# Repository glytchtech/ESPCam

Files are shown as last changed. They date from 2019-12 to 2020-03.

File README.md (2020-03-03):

# ESPCam
## STL and Configuration Files for Glytch's ESPCam Project
If you'd like to support more projects like this one, be sure to check out my [Patreon!](https://patreon.com/glytchtech)

This repo contains all the relevant files to build your own low cost, self contained ESPCam! Bill of Materials with relevant (Amazon Affiliate) links down below! 

# Camera Parts BOM: 
All links are as of December 17th, 2019
* $8.50ea ESP32 Cam Module: https://amzn.to/2Z2IYp7
* $2.50ea u.FL to SMA pig tail: https://amzn.to/2uKZqPQ
* $1.70ea Stubby Antenna 3dbi: https://amzn.to/2MbvqlQ
* $0.90ea TP4056 Battery Module: https://amzn.to/34w5ZBW
* Free 18650 Cell: Recycled from bad laptop battery 
* $7.99 CP2102 UART Programmer: https://amzn.to/2MavQcj

# Cae Parts BOM: 
All links are as of March 2nd, 2020
* $3.50ea (Needs 1) Main Buck Converter: https://amzn.to/2TzlfKO
* $1.55ea (Needs 1) 24V Panel Mount LED: https://amzn.to/2wlrav6
* $1.10ea (Needs 1) WaterProof Panel Switch: https://amzn.to/2wlrav6
* $3.63ea (Needs 2) SMA Antenna Extensions: https://amzn.to/2Tyl5U8
* $Raspberry Pi 4: https://amzn.to/39iwxKb
* WiFi Pineapple Tetra: https://shop.hak5.org/products/wifi-pineapple?variant=11303845317

A couple M3x6 screws and some super glue are also needed for assembly
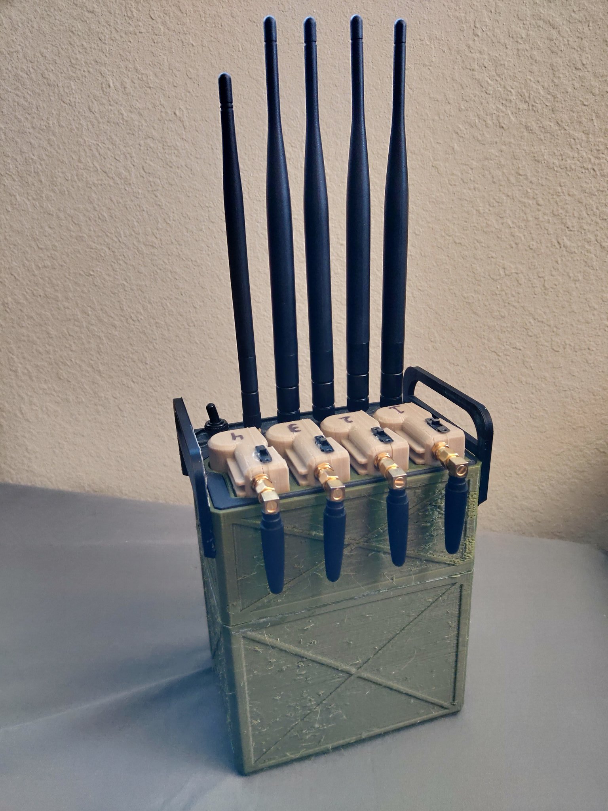
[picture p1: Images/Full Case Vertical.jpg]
Full Case Vert

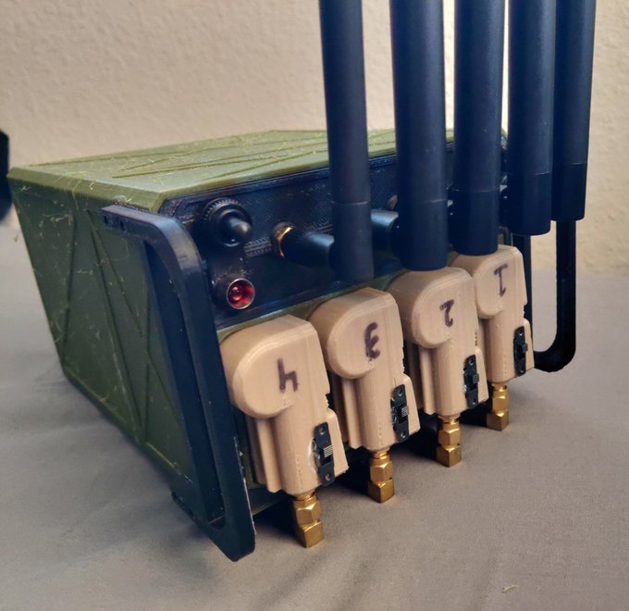
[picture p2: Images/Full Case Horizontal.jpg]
Full Case Horizontal

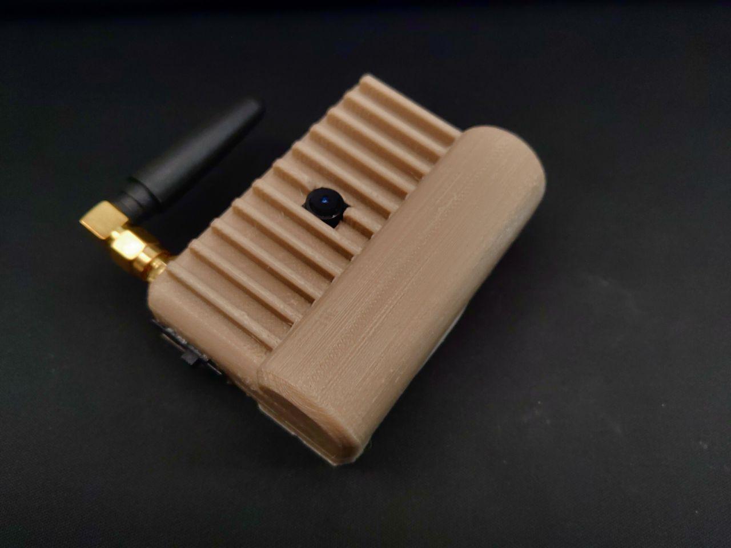
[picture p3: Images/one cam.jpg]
One Cam

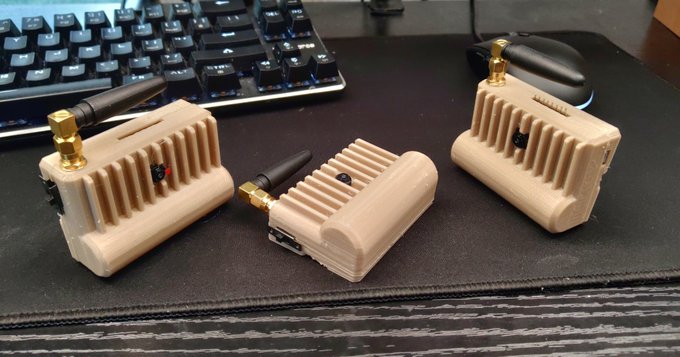
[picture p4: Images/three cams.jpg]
Three Cams

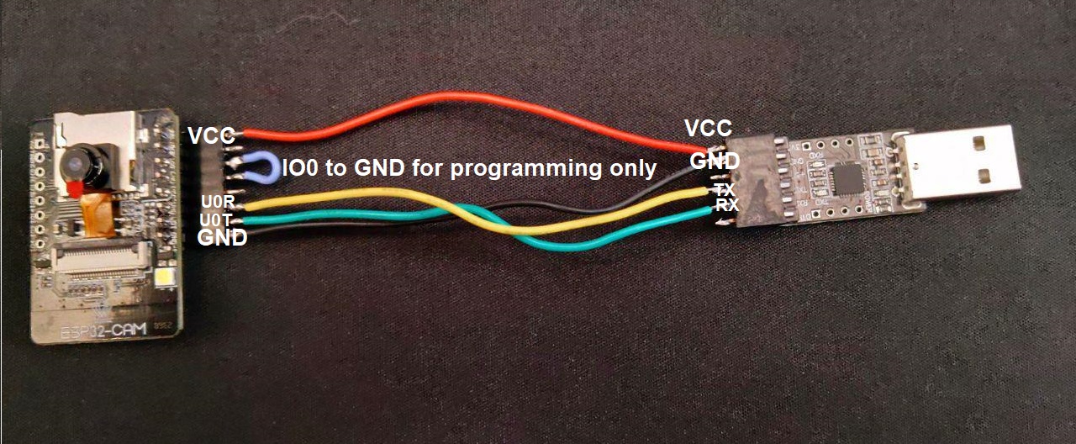
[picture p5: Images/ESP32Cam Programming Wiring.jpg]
Programmer Wiring


This post may contain affiliate links, which means I may receive a small commission if you choose to purchase through links I provide (at no extra cost to you). Thank you for supporting the work I put into this content!

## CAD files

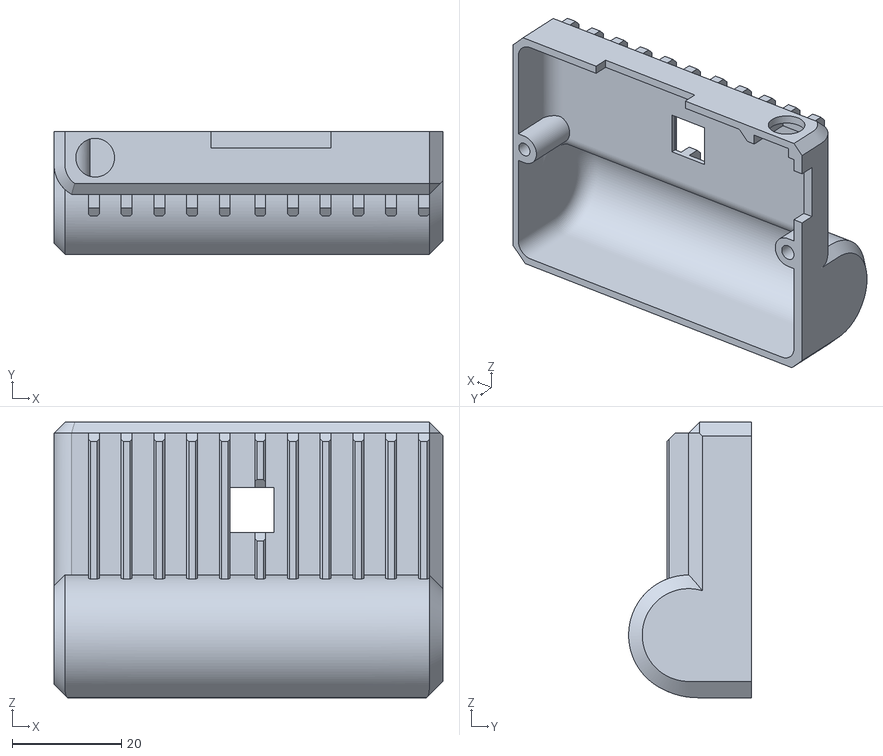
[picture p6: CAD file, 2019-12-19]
STL Files/Main Body.stl
71.3 x 22.5 x 50.5

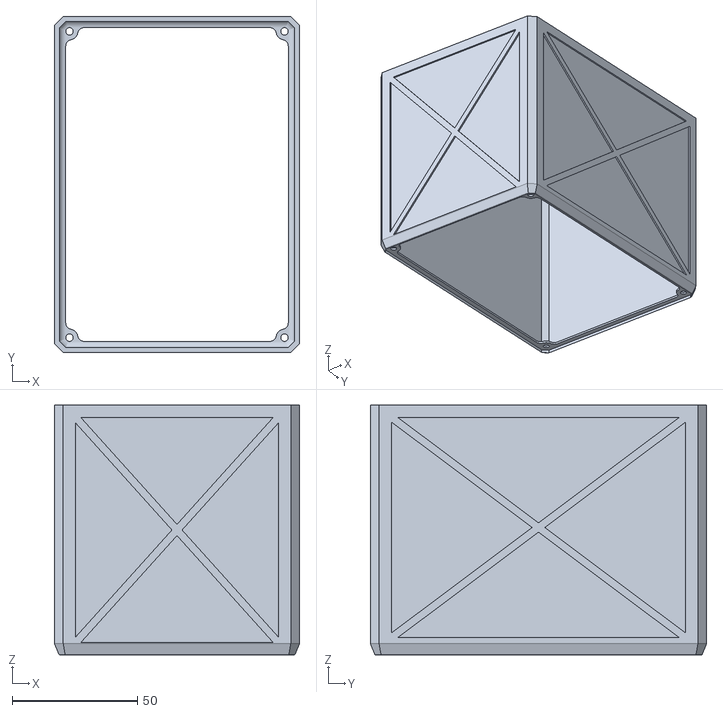
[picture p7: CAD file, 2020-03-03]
STL Files/Full Case/Full Case Bottom.stl
98.0 x 134.5 x 100.0

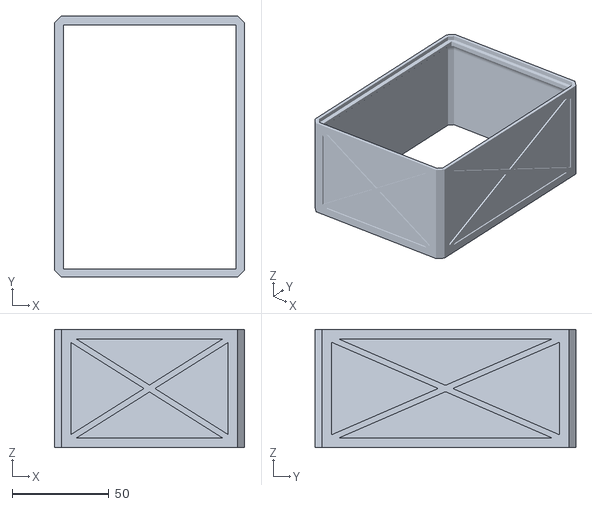
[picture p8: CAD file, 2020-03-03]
STL Files/Full Case/Full Case Top.stl
98.0 x 134.5 x 61.0

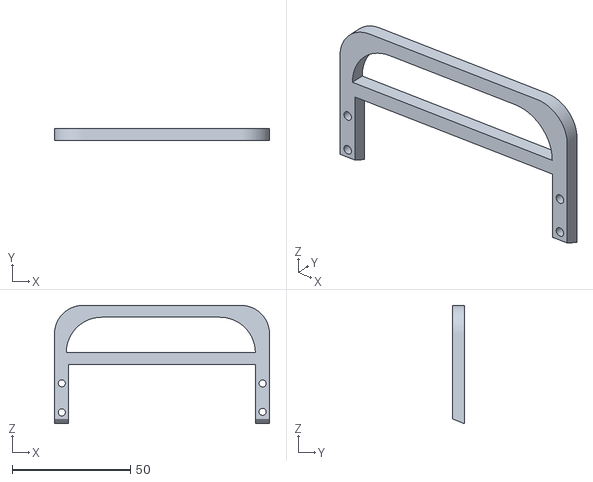
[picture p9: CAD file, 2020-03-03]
STL Files/Full Case/Handle x2.stl
91.0 x 5.00 x 50.0

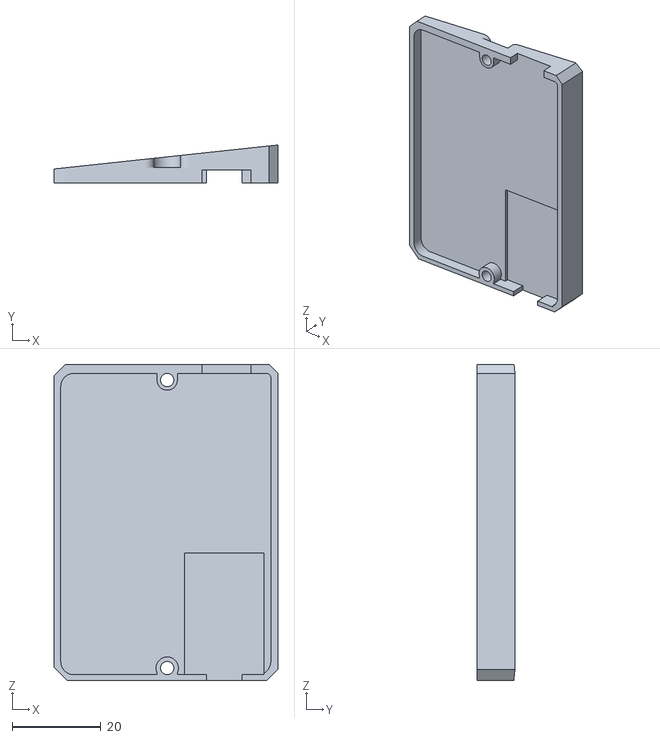
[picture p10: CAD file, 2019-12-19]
STL Files/Back Plate.stl
50.5 x 8.58 x 71.3

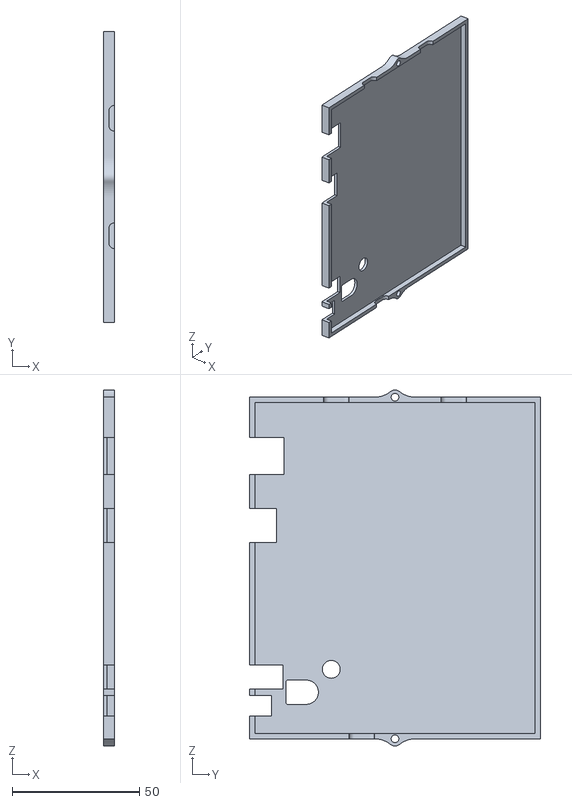
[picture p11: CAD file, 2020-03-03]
STL Files/Full Case/Tetra Low Pro Top.stl
4.50 x 114.0 x 139.6

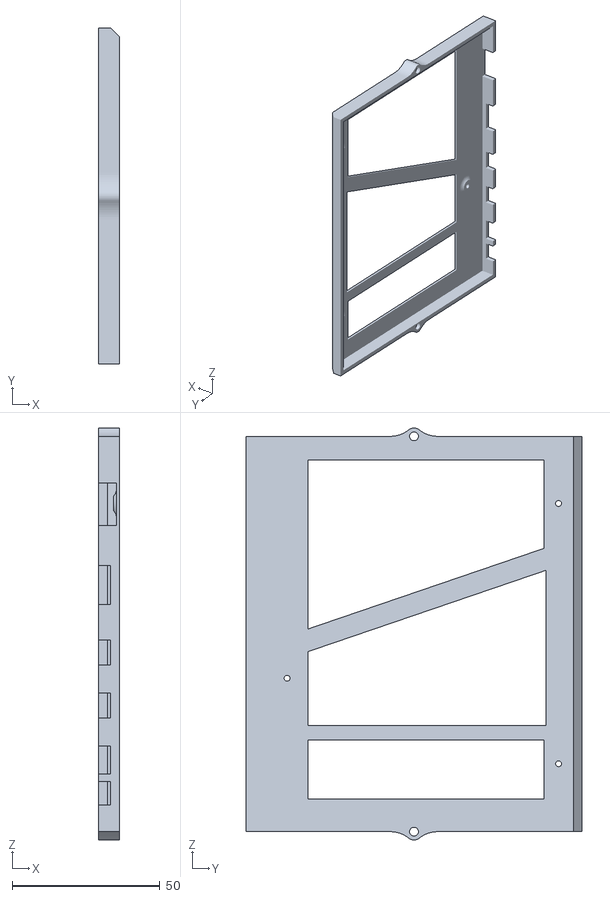
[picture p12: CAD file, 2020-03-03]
STL Files/Full Case/Tetra Low Pro Bottom.stl
7.00 x 114.0 x 139.6

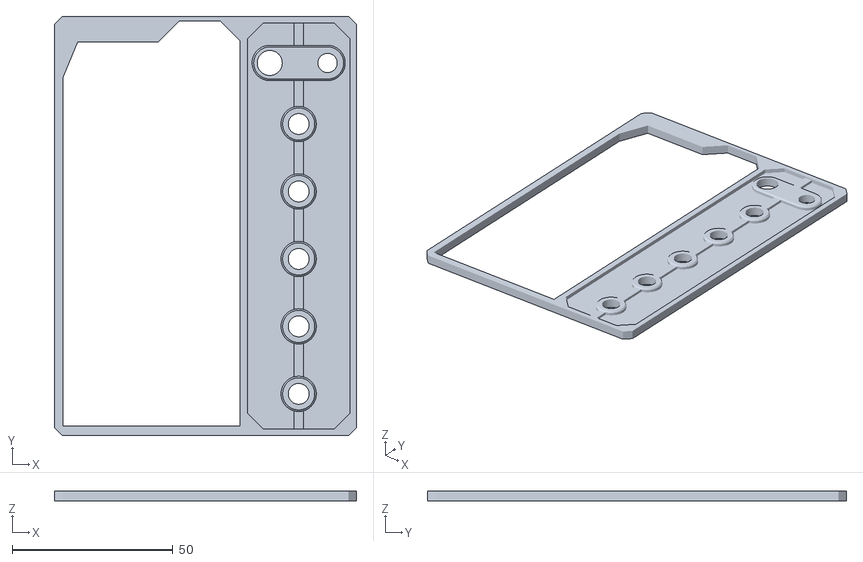
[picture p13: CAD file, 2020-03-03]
STL Files/Full Case/Top Plate.stl
94.0 x 130.5 x 3.20

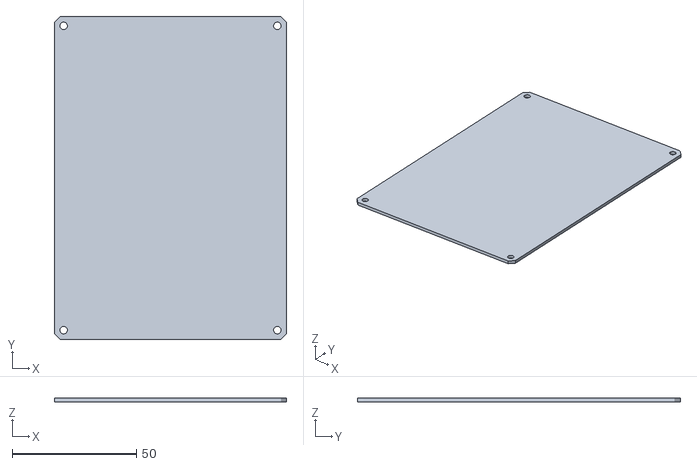
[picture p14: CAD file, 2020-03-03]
STL Files/Full Case/Bottom Plate.stl
93.5 x 130.0 x 1.50

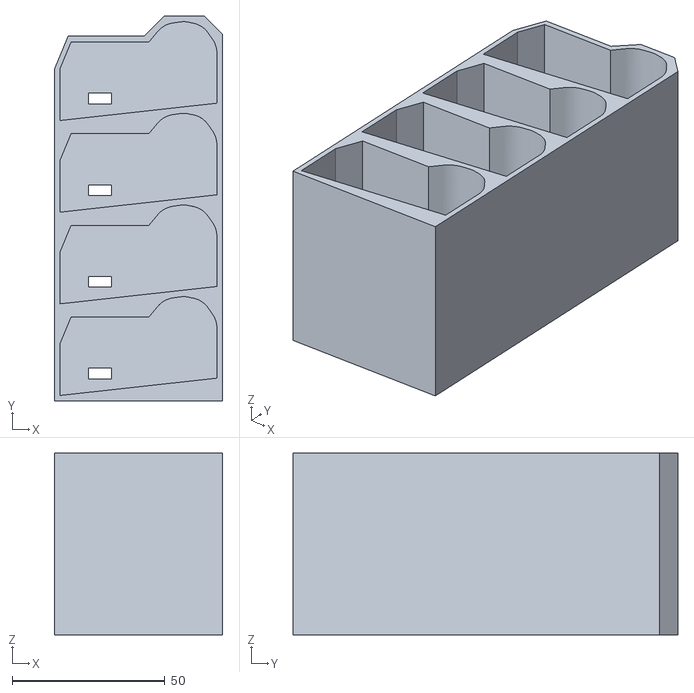
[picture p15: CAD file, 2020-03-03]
STL Files/Full Case/Camera Carrier.stl
55.0 x 126.0 x 59.5

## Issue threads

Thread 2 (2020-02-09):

Missing wiring of the different elements

ppmt, 2020-02-09:
Hello,
I am trying to assemble the unit but was wondering if you could put a diagram showing how to wire the parts together?
It looks very cool so thank your for your project

FelixATR, 2020-03-09:
On the esp-cam module itself only 2 pads are used internally "GND" and "5V". These are labeled on the same side of my board as the camera connector.
On the battery charger module the four pads opposite the micro usb connector are OUT+, B+, B-, and OUT-. Lastly we have 2 pins for the switch and two for the battery terminals.

Wiring:
- GND > OUT-
- 5V > Switch
- Switch > OUT+
- B+ > Battery Positive (+)
- B- > Battery Negative (-)

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

ppmt, 2020-03-09:
Brilliant
Thank you so much for taking the time to make a details description

jusweisq, 2020-06-07:
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

What voltage regulator are you using? Your picture is super helpful. https://randomnerdtutorials.com/power-esp32-esp8266-solar-panels-battery-level-monitoring/ includes the basics, but they list a different LDOs than the above picture. I did not see the device included in Glytch's list June2020, but briefly mentions a switch in his video. Other ESP32 cam projects also leave off the voltage regulator.

jusweisq, 2020-06-07:
While your pictures super helpful, both the diagram and the picture have  the cables going to the 5v side of the ESP32 cam, wouldn't the 3.3 volt side desired? the battery is 3.6V, the voltage regulator drops it to 3.3V so why cable up the 5V? Glytch has the cables going to the 5V side in his video as well.

FelixATR, 2020-06-08:
> While your pictures super helpful, both the diagram and the picture have the cables going to the 5v side of the ESP32 cam, wouldn't the 3.3 volt side desired? the battery is 3.6V, the voltage regulator drops it to 3.3V so why cable up the 5V? Glytch has the cables going to the 5V side in his video as well.

Actually, this is more than a simple voltage regulator. It is designed to be the controller for an18650 based battery bank for 5v charging. As such it outputs 5vdc not 3.3vdc. I believe you might be able to use a simple buck converter to step down from the 3.6v to 3.3, but you won't have the battery protection or charging included in this board.

jusweisq, 2020-06-08:
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

What is the device? There are two kinds of TP4056s, the kind Glytch recommended was the microUSB input that included a DW01 chip that provides protection for over discharge or over current, as opposed to the miniUSB version TP4096. With the device you used, what protection does it have, is it beyond the DW01 chip? I would look up before asking the question, but cannot find anything close. I watched this video to learn how to soder the TP4096 and it included the bit about the DW01 chip, https://www.youtube.com/watch?v=cTzu8LSSqVY&t=940s.  Thank you for explaining that the device is a step up convertor from 3.3 Vto 5V.

FelixATR, 2020-06-08:
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

The board is listed in Glytch's writeup as part of the BOM (Bill of Materials)

jusweisq, 2020-06-08:
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

I wish it was! I just double checked and it is not.

Camera Parts BOM:
All links are as of December 17th, 2019
* $8.50ea ESP32 Cam Module: https://amzn.to/2Z2IYp7
* $2.50ea u.FL to SMA pig tail: https://amzn.to/2uKZqPQ
* $1.70ea Stubby Antenna 3dbi: https://amzn.to/2MbvqlQ
* $0.90ea TP4056 Battery Module: https://amzn.to/34w5ZBW
* Free 18650 Cell: Recycled from bad laptop battery
* $7.99 CP2102 UART Programmer: https://amzn.to/2MavQcj

FelixATR, 2020-06-09:
You just pasted the correct and active link to the board.  "$0.90ea TP4056 Battery Module: https://amzn.to/34w5ZBW"  is the right line item.

jusweisq, 2020-06-09:
> You just pasted the correct and active link to the board. "$0.90ea TP4056 Battery Module: https://amzn.to/34w5ZBW" is the right line item.

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

Not the battery module, the device between the battery module and the ESP32 cam. In the first link I shared another site that had the device as a voltage regulator. You mentioned that the “switch” increased voltaged and was not a LDO. I searched for those devices and could not find a model. Attached is a picture of the device in question. That device is not included in the TP4056 purchase nor is the device in the BOM.

FelixATR, 2020-06-09:
Ahh.. the switch is a simple slide switch. Any switch you have or source that is similar dimensions would work. The ones I used were SPDT (single pull double throw) and measured roughly 5mmx10mm
Some have tabs to let you secure them easier, some do not. You could also use SPST (single pull single throw) as only 2 of the three pins are used anyway. If you search ebay or ali-express for spdt slide switch you should see lots of options. This component does not make any changes to voltage or amperage. It simply acts as a switch.

oupala, 2021-01-23:
@FelixATR As far as I know, the TP4056 is ouputting around 4.2v (exactly 4.1v in my case).

The wires are connected to GND and 5v of the ESP32. Is it enough to *feed* the ESP32 with 4.1v/4.2v when it require 5v?

Sacto43, 2021-01-23:
Nope.  It needs TTL logic to funtion to which is 0 to 5 VDC.  CHeck the
poser supply.

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

oupala, 2021-01-24:
@Sacto43 I don't understand your aswer. Can you please elaborate?

Do you mean that the whole system is not working?

FelixATR, 2021-01-24:
> @FelixATR As far as I know, the TP4056 is ouputting around 4.2v (exactly 4.1v in my case).
>
> The wires are connected to GND and 5v of the ESP32. Is it enough to _feed_ the ESP32 with 4.1v/4.2v when it expects 5v?

The input voltage goes through a 1117 linear regulator on the board which smoothes the signal and reduces it to a steady 3.3vdc anyway. This means the 4.1 or 4.2 vdc output from the battery charging circuit should be sufficient to power the esp-cam. In practice, I have not seen any issues with my boards.

Sacto43, 2021-01-25:
I have no idea who ya'll are.  But I love the questions.  Keep em coming!

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

oupala, 2021-01-25:
> The input voltage goes through a 1117 linear regulator on the board which smoothes the signal and reduces it to a steady 3.3vdc anyway. This means the 4.1 or 4.2 vdc output from the battery charging circuit should be sufficient to power the esp-cam. In practice, I have not seen any issues with my boards.

When you speak about *the board*, are you talking about the TP4056 board? Or the ESP32 board?

To be clear, should the ESP32 be connected to the 5v pin (as shown on the previous schema), or to the 3.3v pin?

FelixATR, 2021-01-25:
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

the esp32. I figured that would have been clear from context.  If you would like more specific details on how the esp32 works or is used regarding its pinout, the documentation is widely available. I did not work on this project. I saw Glytch's awesome project on youtube, followed his steps and it worked. Everything else I have tracked down here was done with a couple minutes of google searching.

oupala, 2021-01-26:
Thanks for your answer.

I have to say that I have looked on the internet, and I've found a lot of other electronic setup using some resistor in addition to the TP4056. That's why I wanted to ask here, where some people had successfully made it working.

On my side, it did not worked as it appears that the ESP32 does not start with the 4.12v of the TP4056 output. However, it does work with my TTL USB adapter that I used to flash the ESP32.

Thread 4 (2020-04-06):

incorrect link in readme

JesseyWhite, 2020-04-06:
24V Panel Mount LED has the wrong link and is a copy of the waterproof switches

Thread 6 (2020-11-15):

Any alternatives UART Board

credmond06, 2020-11-15:
Are there any other alternatives for the CP2102 UART Programmer: https://amzn.to/2MavQcj ? I'm finding it difficult to find an alternative as most other boards I'm finding are 5 pin vs 6 pin.

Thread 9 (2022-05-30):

Camera Circuit diagram

s13t0ttz, 2022-05-30:
There's a programming diagram but not an overall camera circuit diagram on how to connect the battery, charger and esp32 mod. Can you post this?

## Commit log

2020-03-03 Added Full Case STL Files
    [Bottom Plate.stl, Camera Carrier.stl, Full Case Bottom.stl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]
2020-03-03 Add Full Case Images
